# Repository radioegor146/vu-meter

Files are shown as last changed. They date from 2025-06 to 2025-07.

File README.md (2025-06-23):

# vu-meter

Physical VU meter for use with rack audio equipment

Consists of:
- 1 processor board
- 4 indicator boards (2 boards per channel)

## Processor board

The processor board is a simple board with converter from balanced input to unbalanced with 
2 x CH32X035F7P6 MCU to convert from analog domain to digital for output to SPI for shift registers.

## Indicator board

This board consists of 5 74HC595D shift registers for 35 individual LEDs.

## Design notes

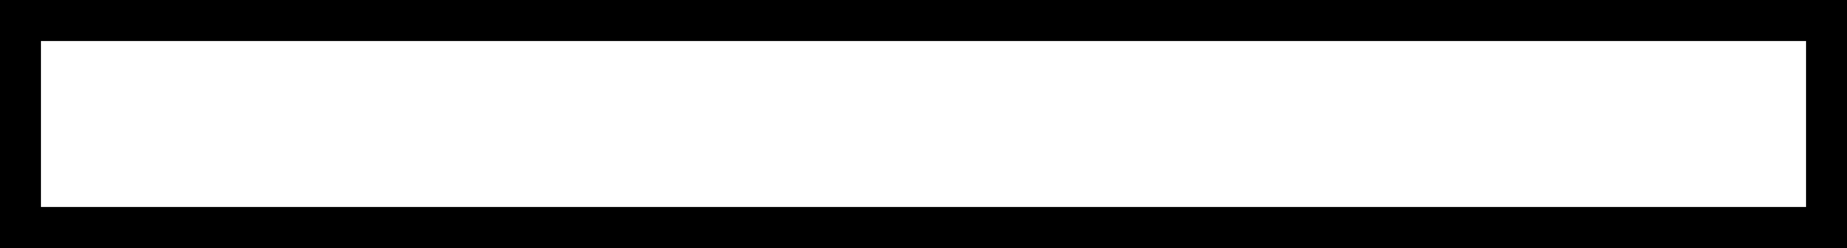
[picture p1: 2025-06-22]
front/panel-transparent-300dpi/cutout.png

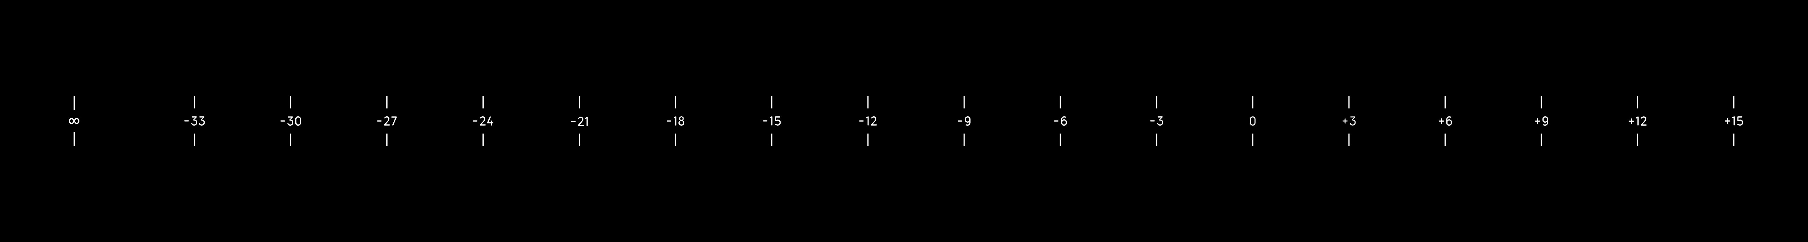
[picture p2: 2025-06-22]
front/panel-cutout-300dpi/foreground.png

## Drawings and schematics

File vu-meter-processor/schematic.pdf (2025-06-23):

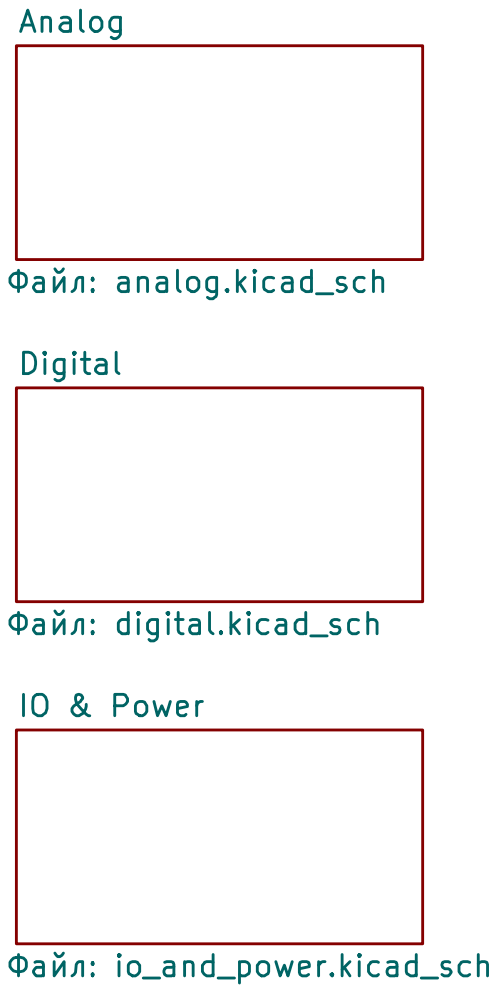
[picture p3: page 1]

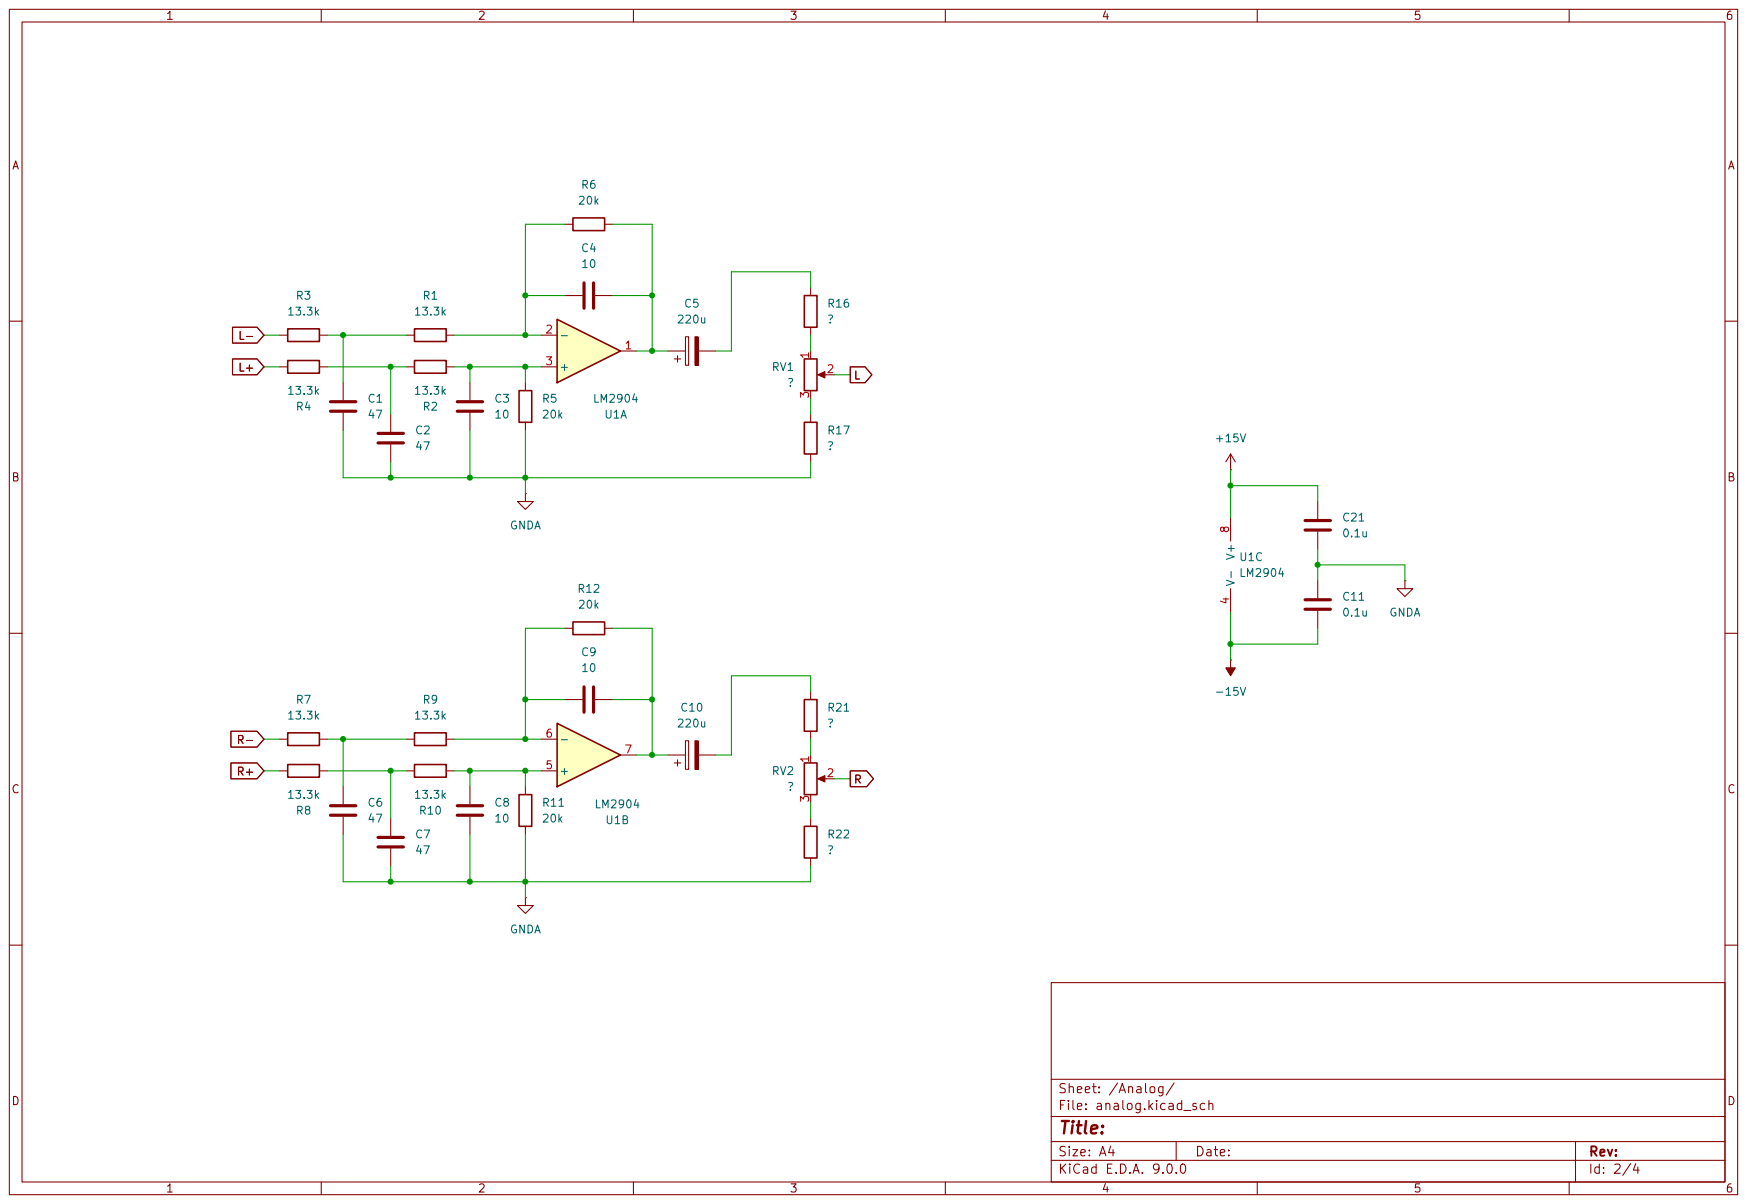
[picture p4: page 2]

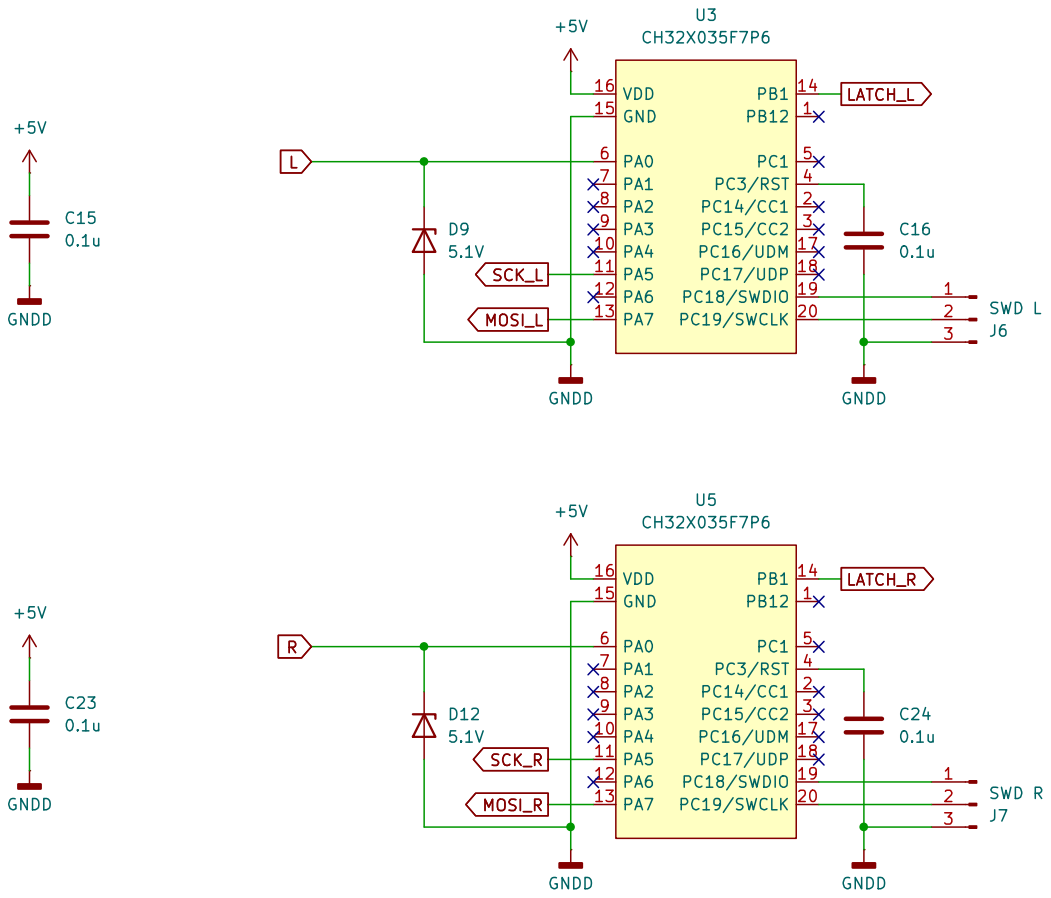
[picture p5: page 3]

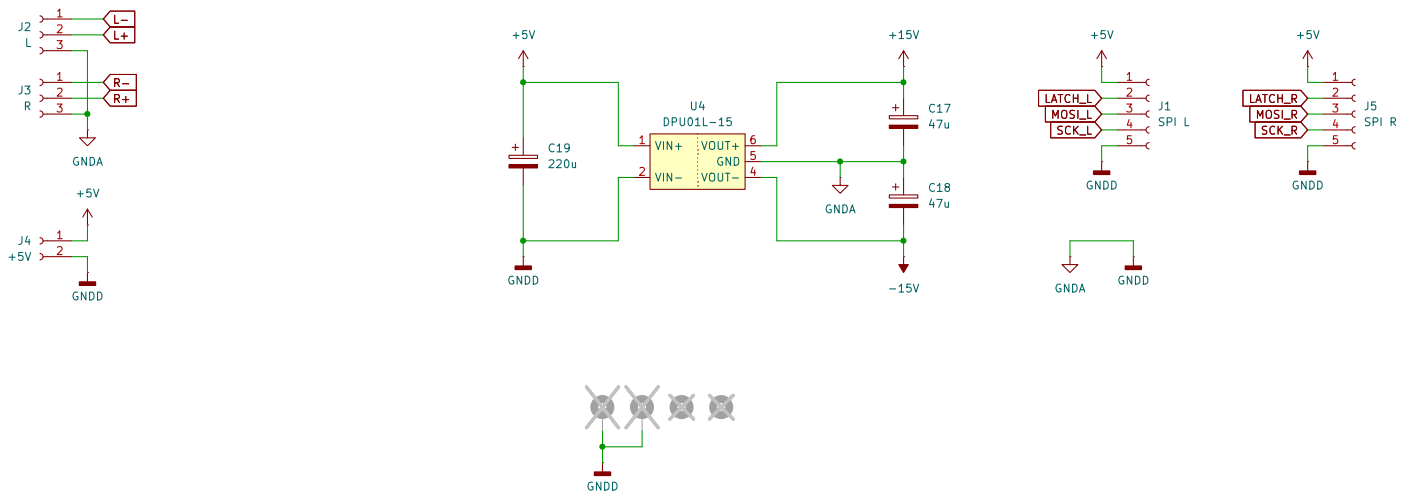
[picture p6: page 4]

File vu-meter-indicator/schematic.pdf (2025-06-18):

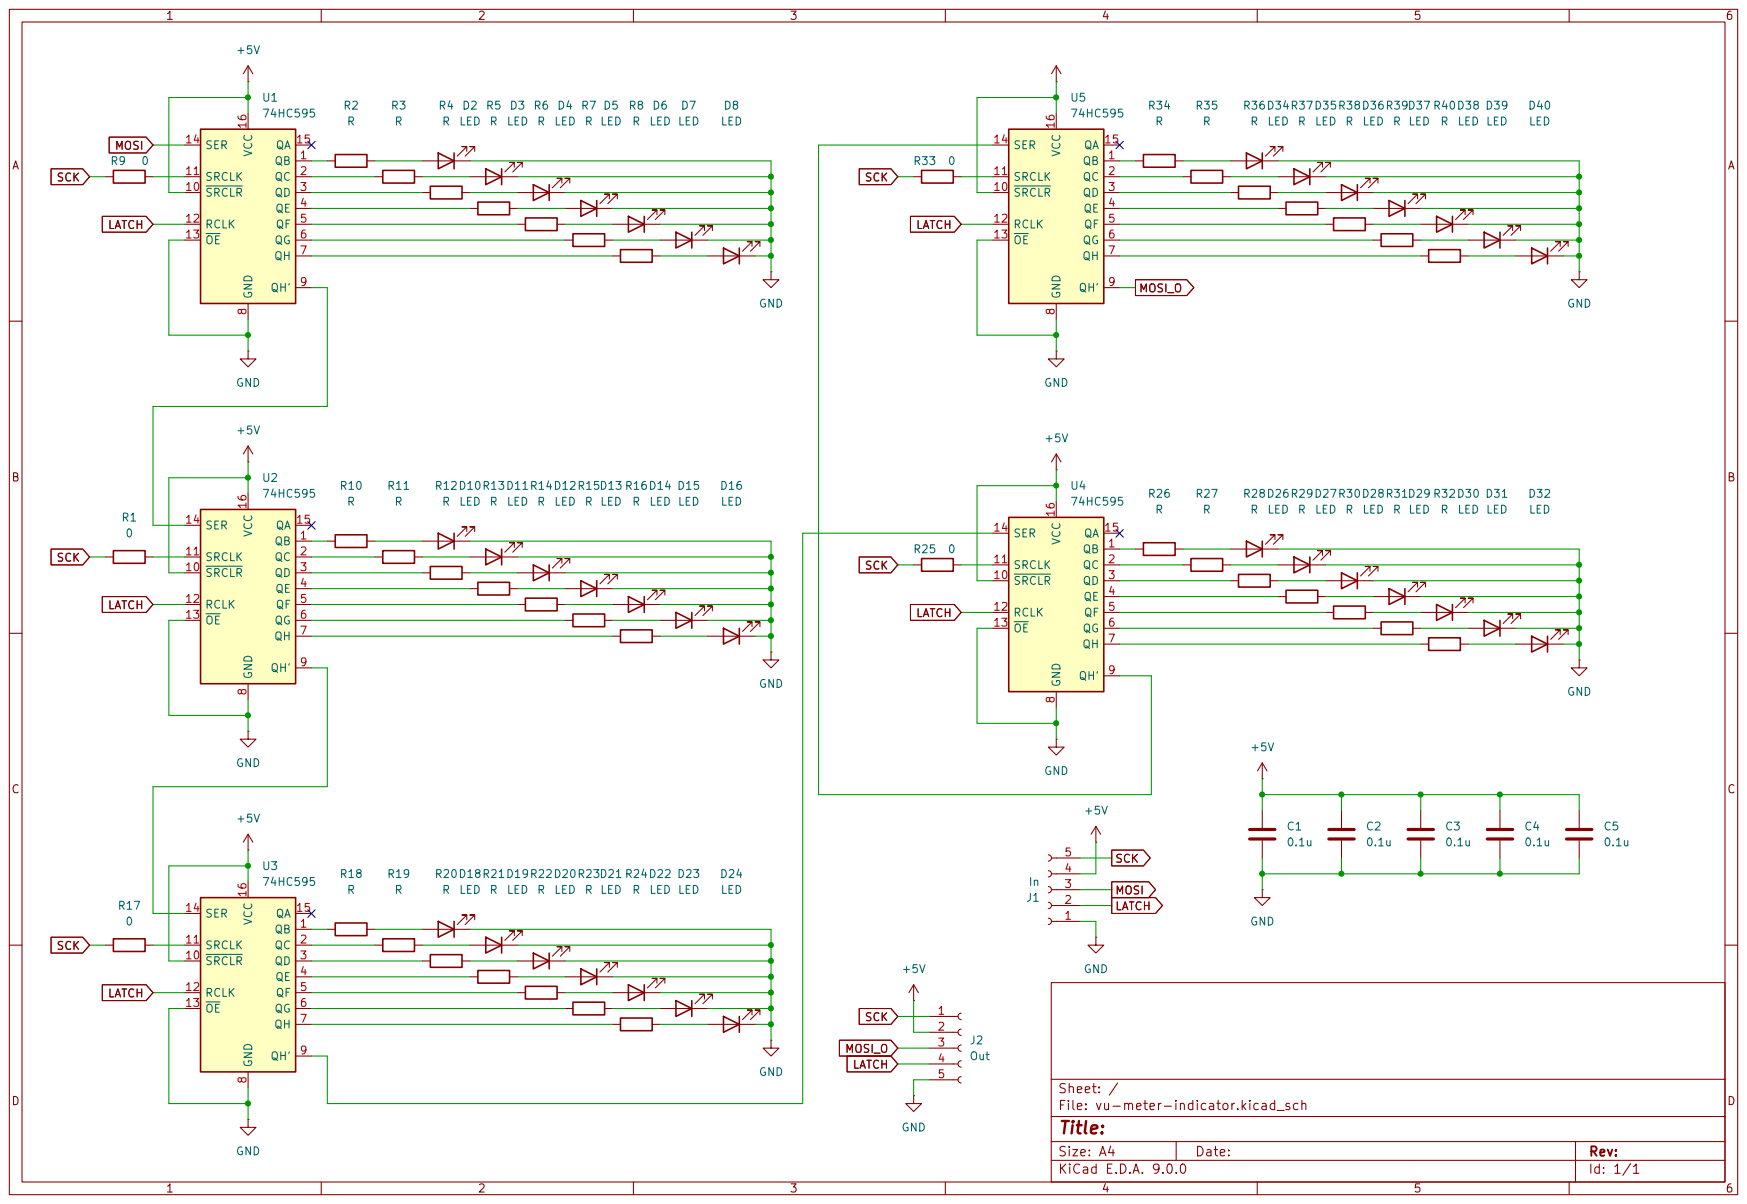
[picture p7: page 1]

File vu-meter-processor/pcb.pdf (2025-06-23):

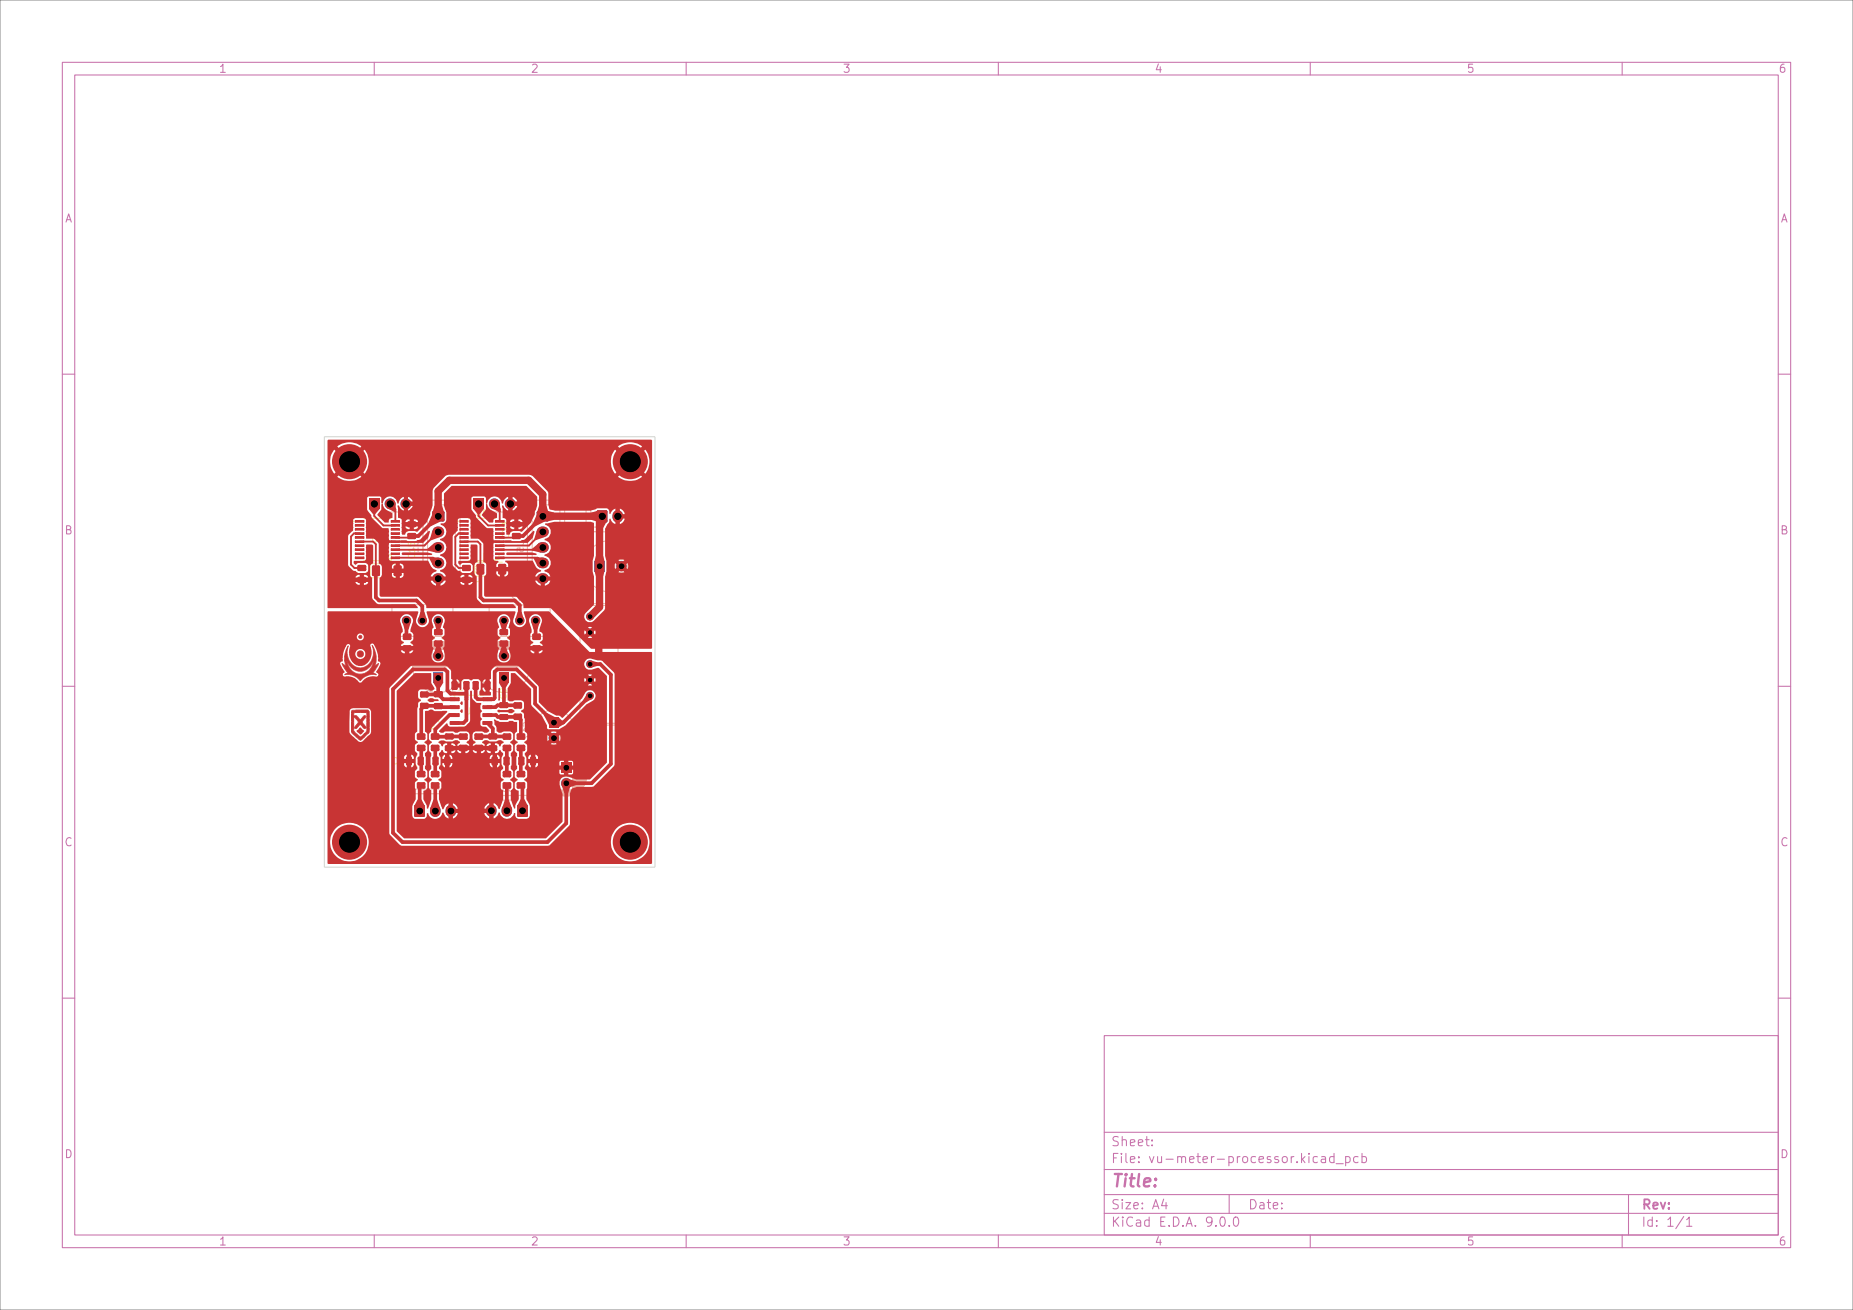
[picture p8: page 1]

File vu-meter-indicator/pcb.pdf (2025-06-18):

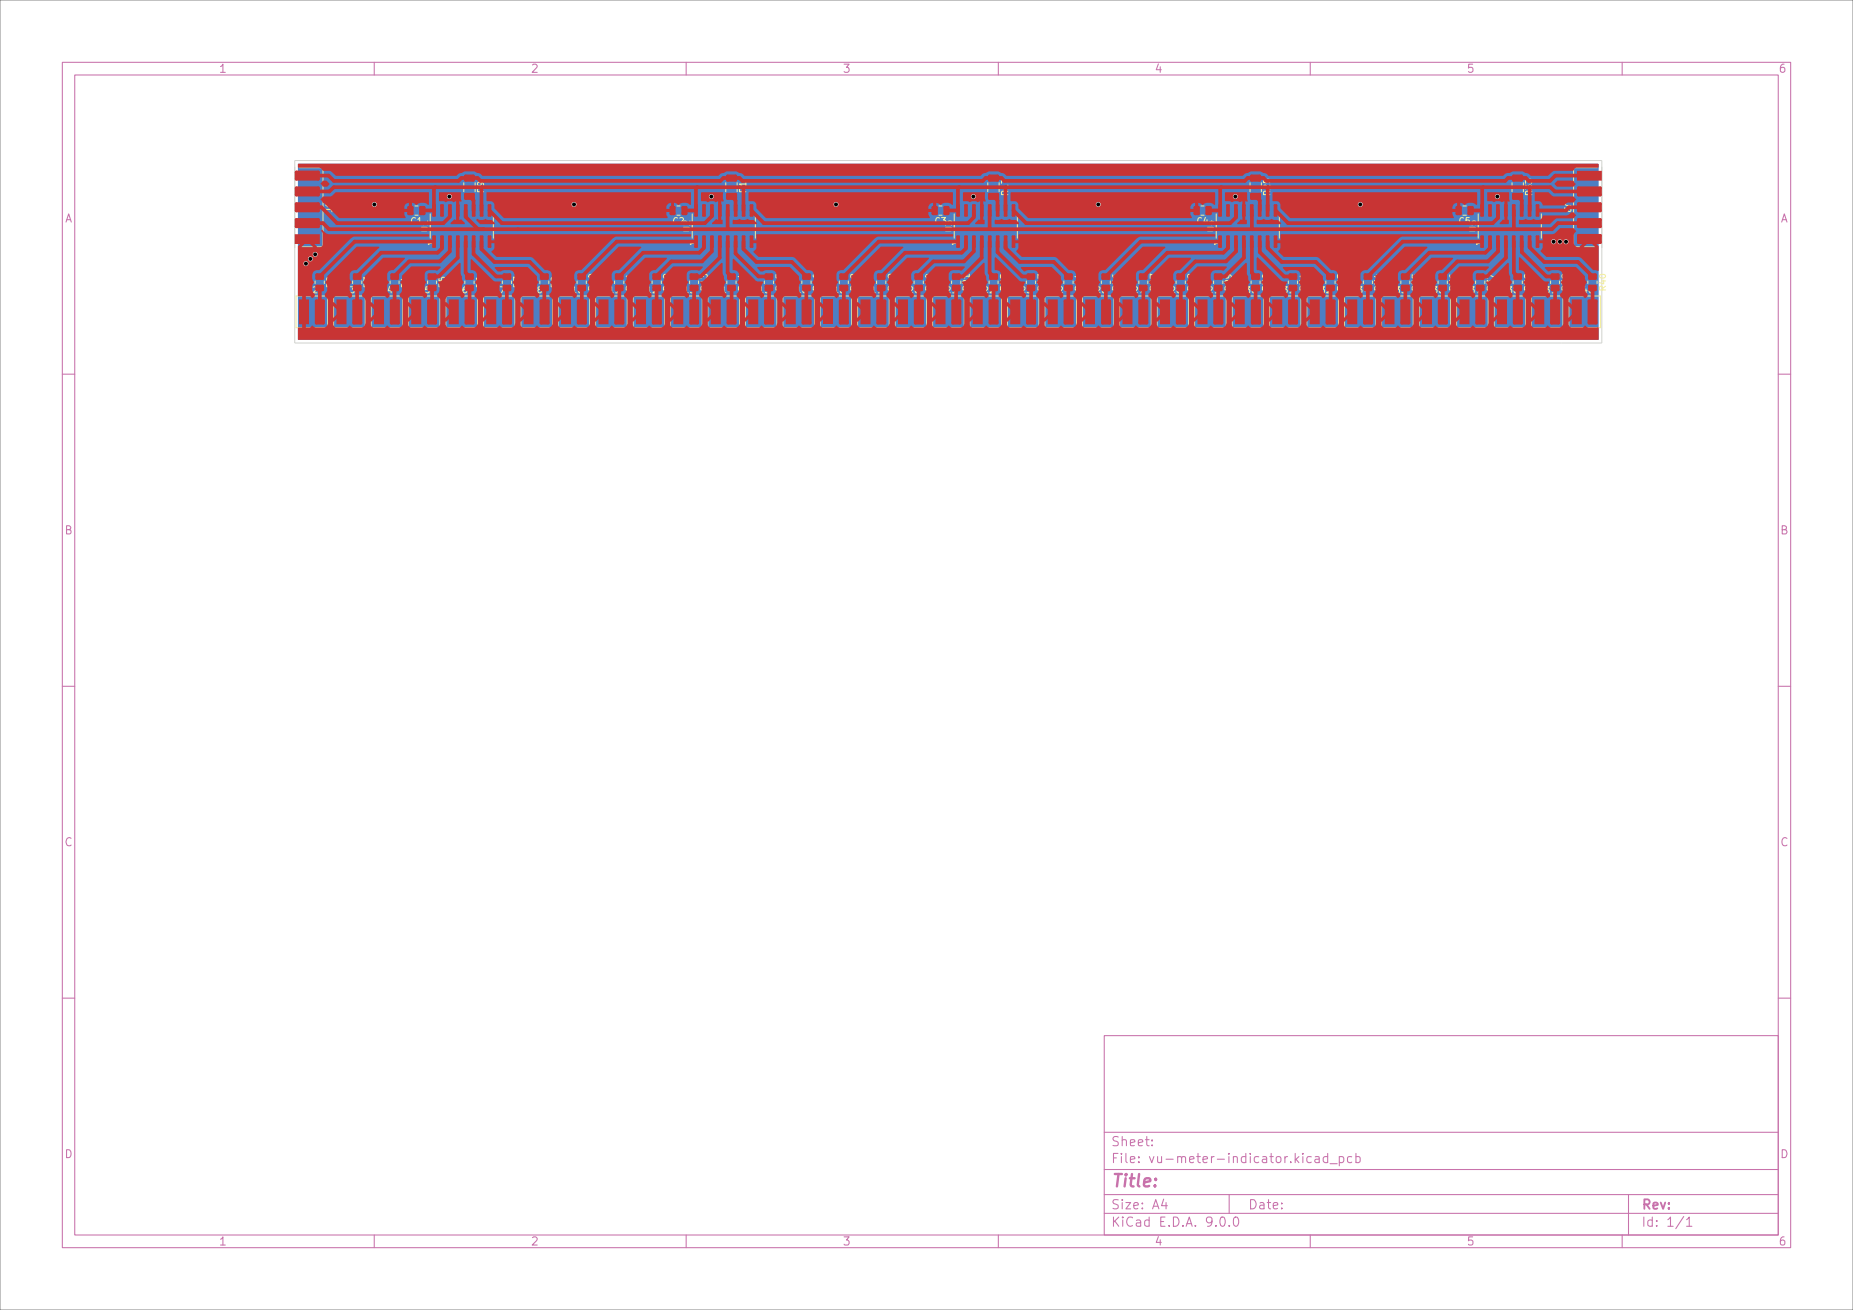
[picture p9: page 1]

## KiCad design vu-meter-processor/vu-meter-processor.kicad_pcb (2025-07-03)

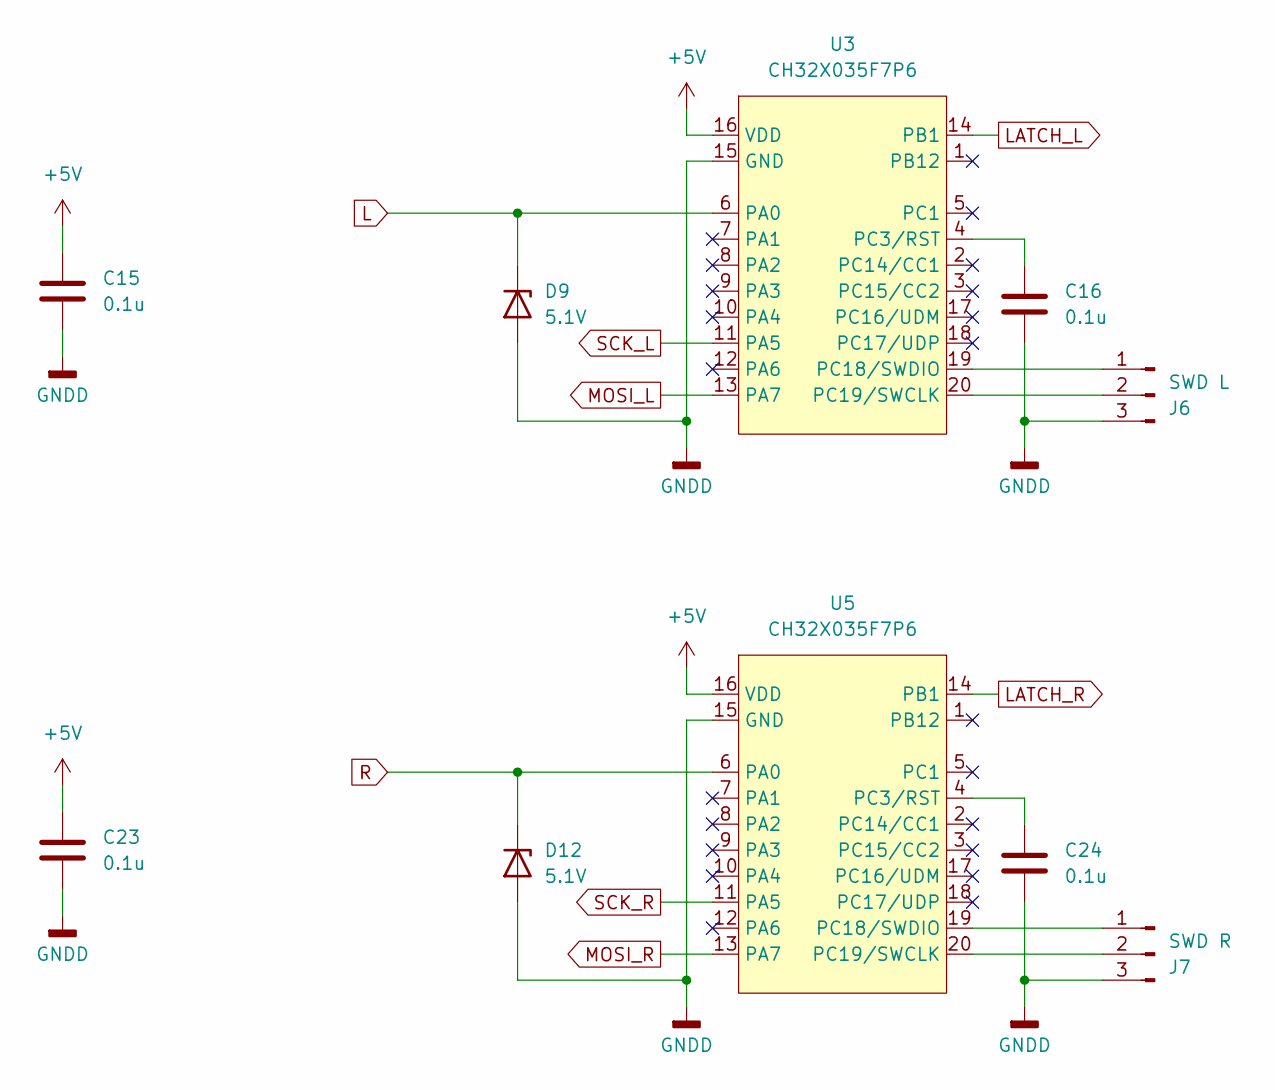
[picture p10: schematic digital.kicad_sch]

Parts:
C15, C16, C23, C24: 0.1u; C_0805_2012Metric
D9, D12: 5.1V; D_MiniMELF
J6: SWD L; PinHeader_1x03_P2.54mm_Vertical
J7: SWD R; PinHeader_1x03_P2.54mm_Vertical
U3, U5: CH32X035F7P6; TSSOP-20_4.4x6.5mm_P0.65mm

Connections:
+5V: C15.1, C23.1, U3.16 (VDD), U5.16 (VDD); also elsewhere on the board
GNDA: C15.2, C16.2, C23.2, C24.2, D9.2 (A), D12.2 (A), J6.3, J7.3, U3.15 (GND), U5.15 (GND); also elsewhere on the board
L: D9.1 (K), U3.6 (PA0); also elsewhere on the board
LATCH_L: U3.14 (PB1); also elsewhere on the board
LATCH_R: U5.14 (PB1); also elsewhere on the board
MOSI_L: U3.13 (PA7); also elsewhere on the board
MOSI_R: U5.13 (PA7); also elsewhere on the board
unnamed: J6.1, U3.19 (PC18/SWDIO)
unnamed: J6.2, U3.20 (PC19/SWCLK)
unnamed: J7.1, U5.19 (PC18/SWDIO)
unnamed: J7.2, U5.20 (PC19/SWCLK)
unnamed: C16.1, U3.4 (PC3/RST)
unnamed: C24.1, U5.4 (PC3/RST)
R: D12.1 (K), U5.6 (PA0); also elsewhere on the board
SCK_L: U3.11 (PA5); also elsewhere on the board
SCK_R: U5.11 (PA5); also elsewhere on the board

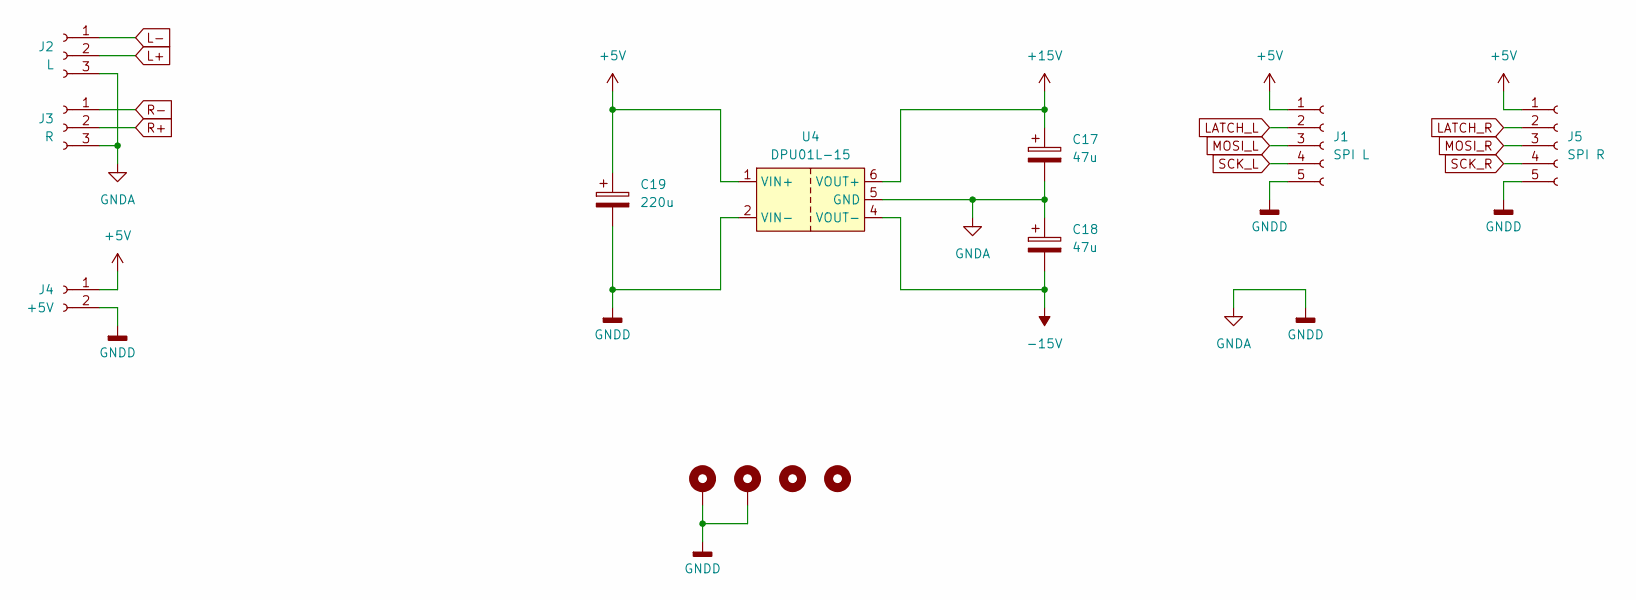
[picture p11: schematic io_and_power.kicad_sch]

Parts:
C17, C18: 47u; CP_Radial_D6.3mm_P2.50mm
C19: 220u; CP_Radial_D8.0mm_P3.50mm
H1, H2, H3, H4: MountingHole_Pad; MountingHole_3.2mm_M3_DIN965_Pad_TopOnly
J1: SPI L; JST_XH_B5B-XH-A_1x05_P2.50mm_Vertical
J2: L; JST_XH_B3B-XH-A_1x03_P2.50mm_Vertical
J3: R; JST_XH_B3B-XH-A_1x03_P2.50mm_Vertical
J4: +5V; JST_XH_B2B-XH-A_1x02_P2.50mm_Vertical
J5: SPI R; JST_XH_B5B-XH-A_1x05_P2.50mm_Vertical
U4: DPU01L-15

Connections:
+5V: C19.1, J1.1, J4.1, J5.1, U4.1 (VIN+); also elsewhere on the board
+15V: C17.1, U4.6 (VOUT+); also elsewhere on the board
-15V: C18.2, U4.4 (VOUT-); also elsewhere on the board
GNDA: C17.2, C18.1, C19.2, H1.1, H2.1, J1.5, J2.3, J3.3, J4.2, J5.5, U4.2 (VIN-), U4.5 (GND); also elsewhere on the board
L+: J2.2; also elsewhere on the board
L-: J2.1; also elsewhere on the board
LATCH_L: J1.2; also elsewhere on the board
LATCH_R: J5.2; also elsewhere on the board
MOSI_L: J1.3; also elsewhere on the board
MOSI_R: J5.3; also elsewhere on the board
R+: J3.2; also elsewhere on the board
R-: J3.1; also elsewhere on the board
SCK_L: J1.4; also elsewhere on the board
SCK_R: J5.4; also elsewhere on the board

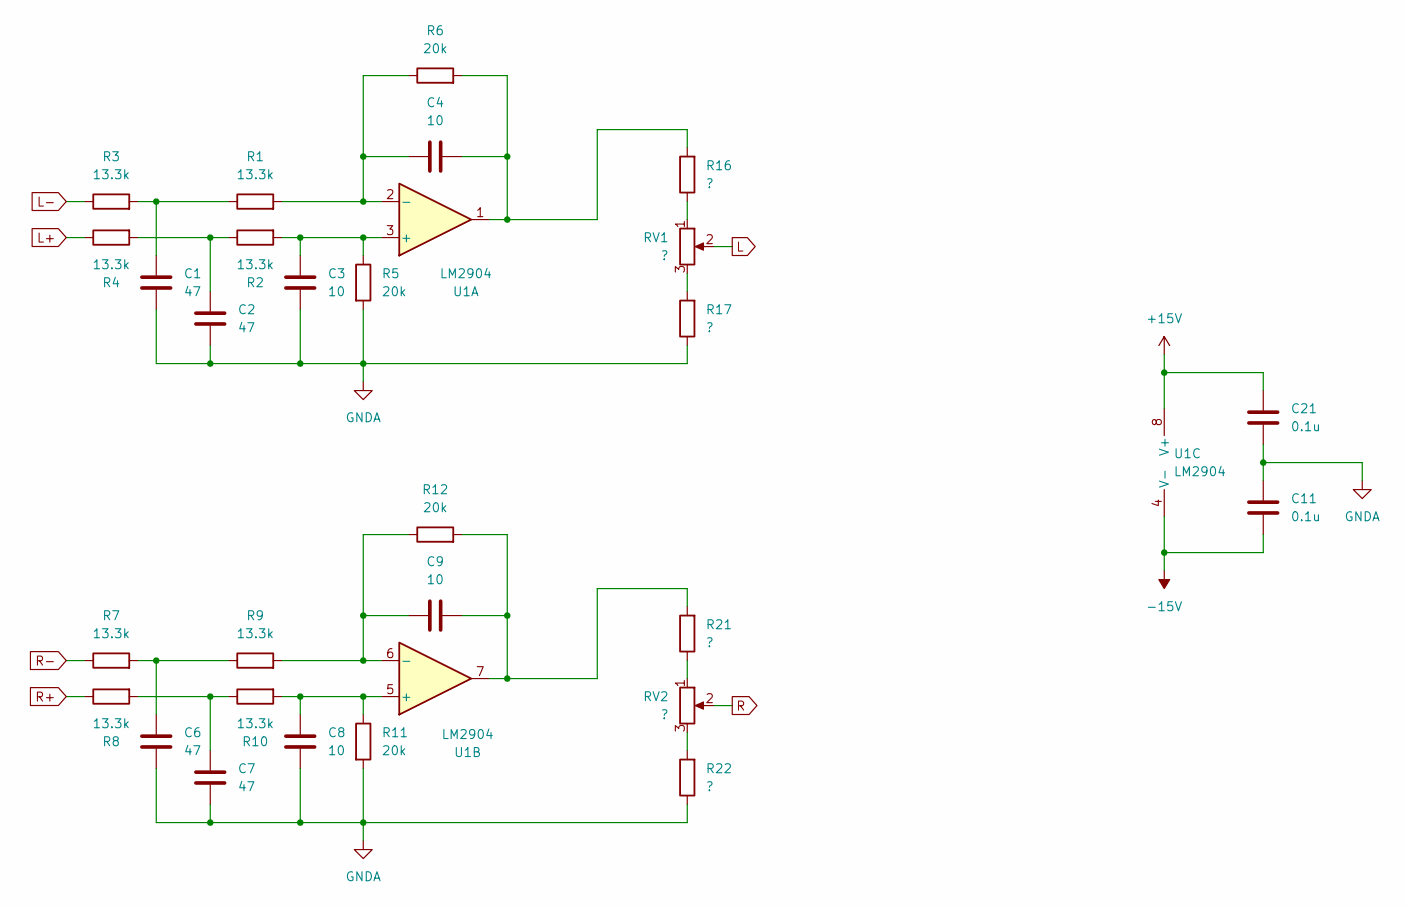
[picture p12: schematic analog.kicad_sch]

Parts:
C1, C2, C6, C7: 47; C_0805_2012Metric
C3, C4, C8, C9: 10; C_0805_2012Metric
C11, C21: 0.1u; C_0805_2012Metric
R1, R2, R3, R4, R7, R8, R9, R10: 13.3k; R_0805_2012Metric
R5, R6, R11, R12: 20k; R_0805_2012Metric
R16, R17, R21, R22: ?; R_0805_2012Metric
RV1, RV2: ?; Potentiometer_Bourns_3296W_Vertical
U1: LM2904; SOP-8_3.9x4.9mm_P1.27mm

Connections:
+15V: C21.1, U1.8 (V+); also elsewhere on the board
-15V: C11.2, U1.4 (V-); also elsewhere on the board
GNDA: C1.2, C2.2, C3.2, C6.2, C7.2, C8.2, C11.1, C21.2, R5.2, R11.2, R17.1, R22.1; also elsewhere on the board
L: RV1.2; also elsewhere on the board
L+: R4.1; also elsewhere on the board
L-: R3.1; also elsewhere on the board
unnamed: C1.1, R1.1, R3.2
unnamed: C2.1, R2.1, R4.2
unnamed: C4.2, R6.2, R16.2, U1.1
unnamed: C6.1, R7.2, R9.1
unnamed: C7.1, R8.2, R10.1
unnamed: C9.2, R12.2, R21.2, U1.7
unnamed: R16.1, RV1.1
unnamed: R17.2, RV1.3
unnamed: R21.1, RV2.1
unnamed: R22.2, RV2.3
unnamed: C3.1, R2.2, R5.1, U1.3 (+)
unnamed: C4.1, R1.2, R6.1, U1.2 (-)
unnamed: C8.1, R10.2, R11.1, U1.5 (+)
unnamed: C9.1, R9.2, R12.1, U1.6 (-)
R: RV2.2; also elsewhere on the board
R+: R8.1; also elsewhere on the board
R-: R7.1; also elsewhere on the board

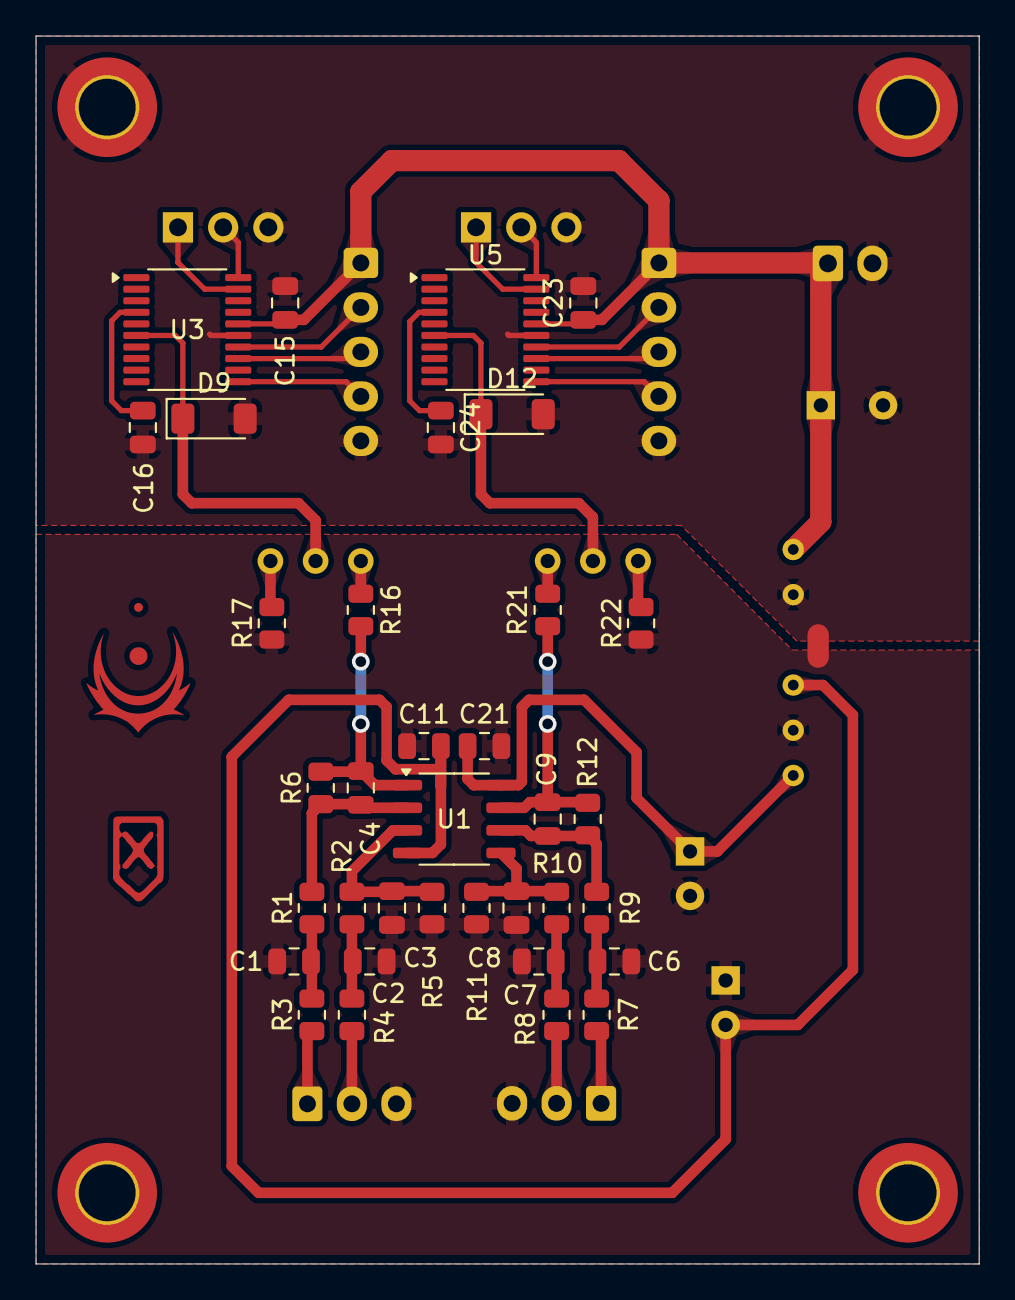
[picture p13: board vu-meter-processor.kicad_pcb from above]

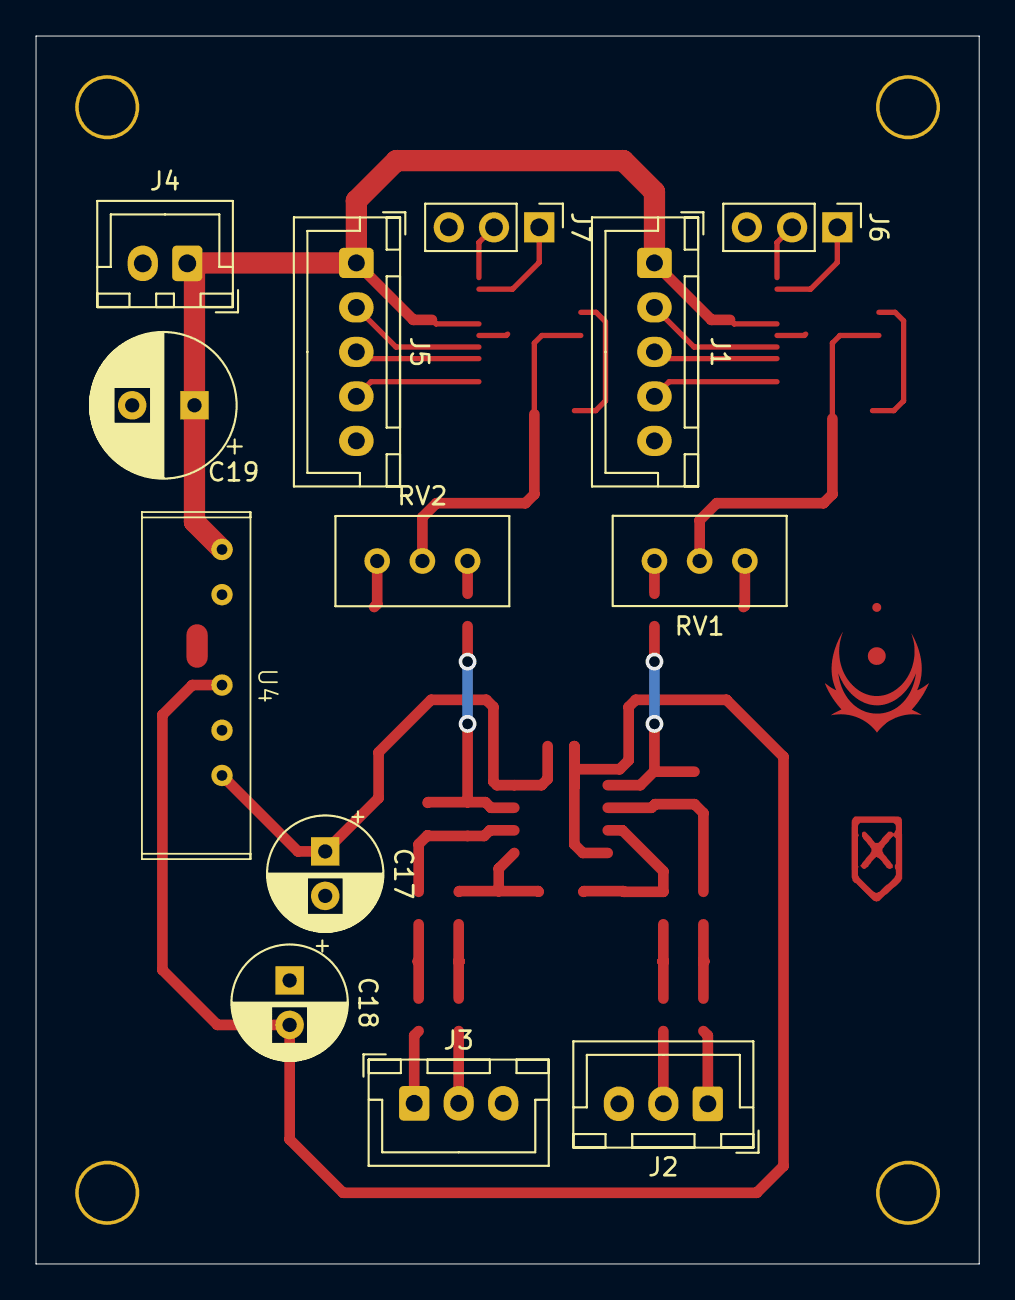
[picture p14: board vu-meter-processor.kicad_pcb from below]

Board: 2 copper layers, 53.0 x 69.0 mm, 52 parts (13 on the bottom side), 36 nets.

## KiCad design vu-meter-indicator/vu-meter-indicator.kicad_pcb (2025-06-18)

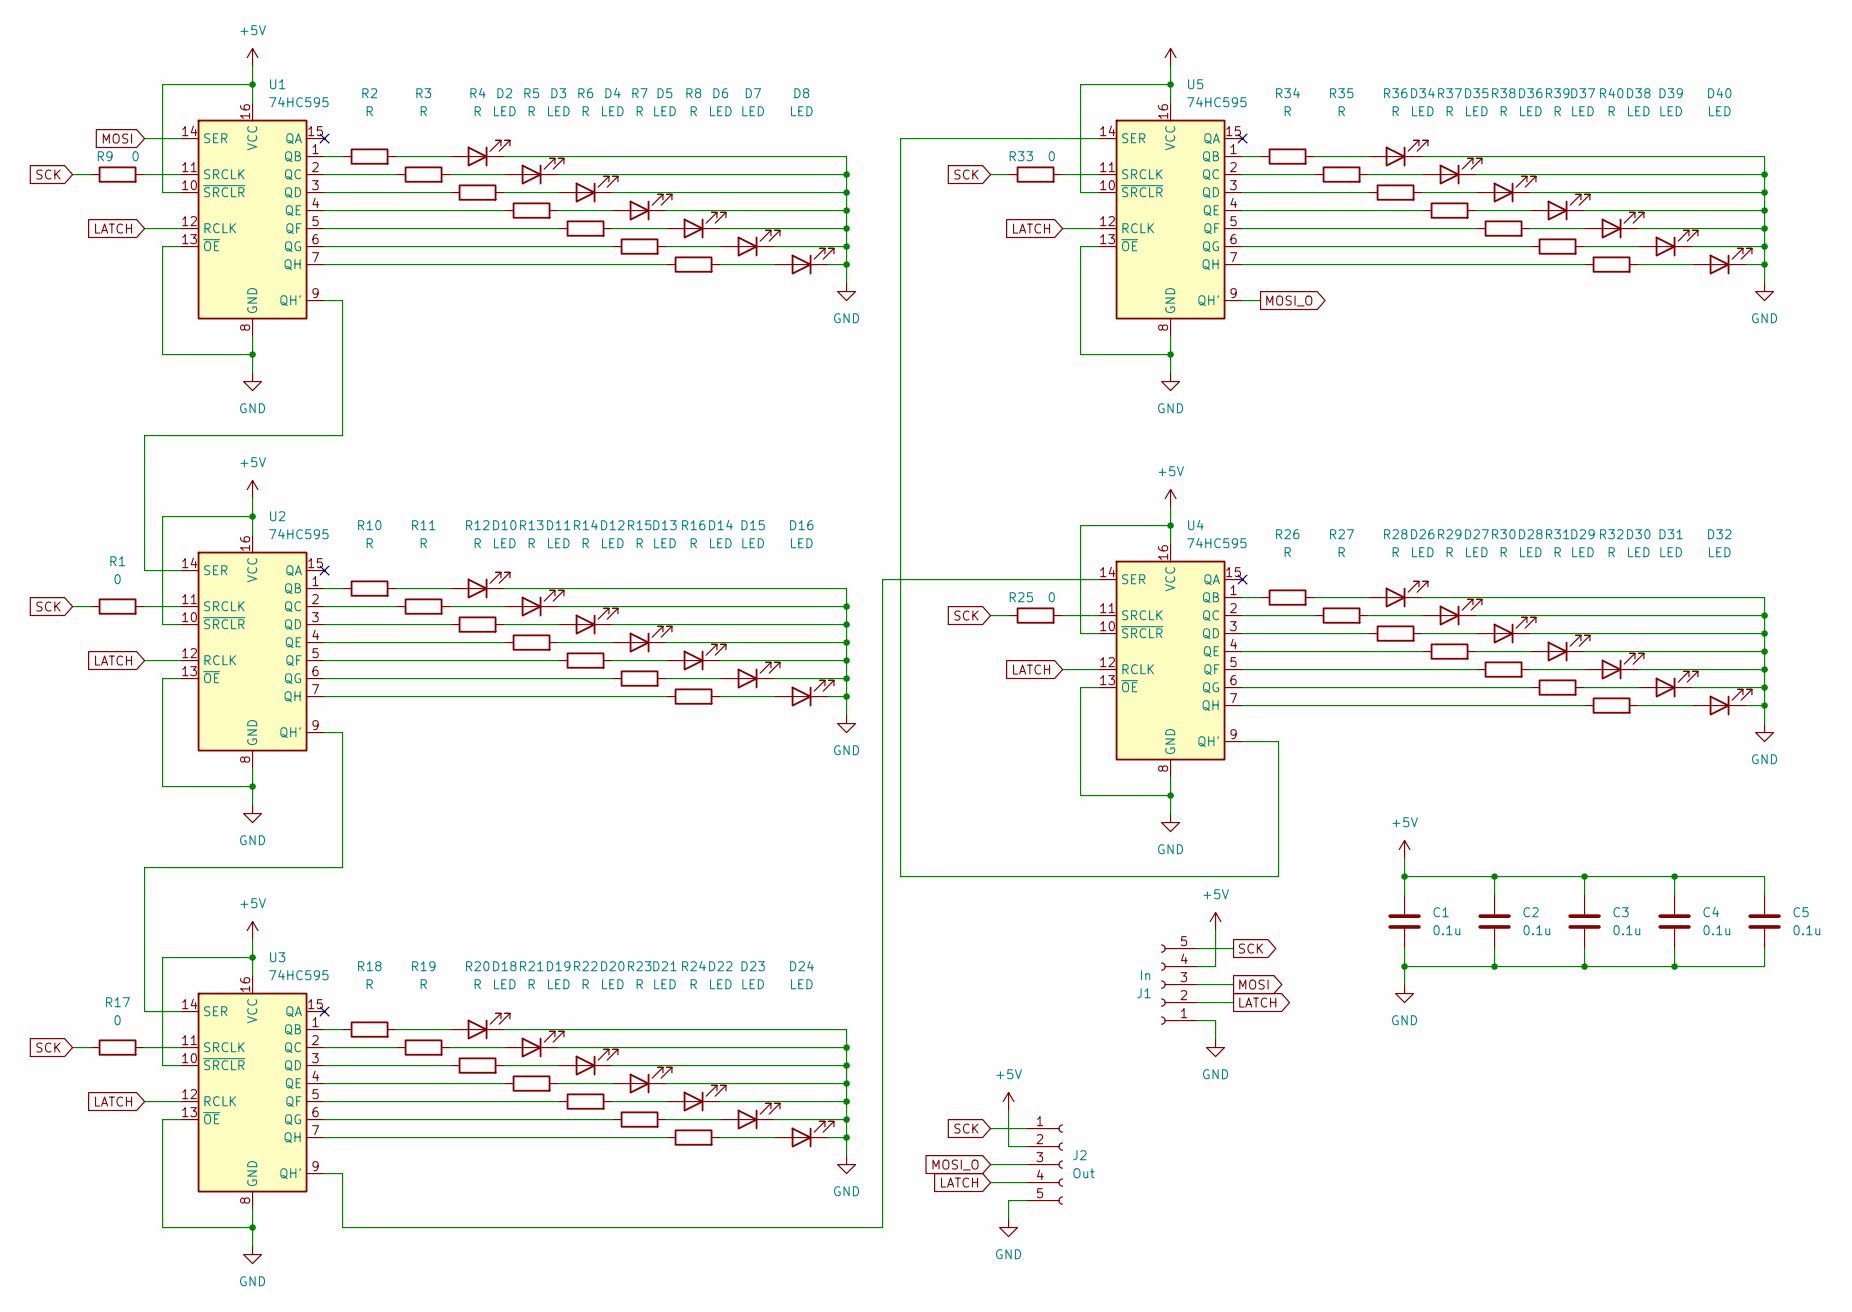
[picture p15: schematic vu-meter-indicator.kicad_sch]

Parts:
C1, C2, C3, C4, C5: 0.1u; C_0805_2012Metric
D2, D3, D4, D5, D6, D7, D8, D10, D11, D12, D13, D14, D15, D16, D18, D19, D20, D21, D22, D23, D24, D26, D27, D28, D29, D30, D31, D32, D34, D35, D36, D37, D38, D39, D40: LED
J1: In; SMD_Connector
J2: Out; SMD_Connector
R1, R9, R17, R25, R33: 0; R_1206_3216Metric
R2, R3, R4, R5, R6, R7, R8, R10, R11, R12, R13, R14, R15, R16, R18, R19, R20, R21, R22, R23, R24, R26, R27, R28, R29, R30, R31, R32, R34, R35, R36, R37, R38, R39, R40: R; R_0805_2012Metric
U1, U2, U3, U4, U5: 74HC595; SOP-16_3.9x9.9mm_P1.27mm

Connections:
+5V: C1.1, C2.1, C3.1, C4.1, C5.1, J1.4, J2.2, U1.10 (~SRCLR), U1.16 (VCC), U2.10 (~SRCLR), U2.16 (VCC), U3.10 (~SRCLR), U3.16 (VCC), U4.10 (~SRCLR), U4.16 (VCC), U5.10 (~SRCLR), U5.16 (VCC)
GND: C1.2, C2.2, C3.2, C4.2, C5.2, D2.1 (K), D3.1 (K), D4.1 (K), D5.1 (K), D6.1 (K), D7.1 (K), D8.1 (K), D10.1 (K), D11.1 (K), D12.1 (K), D13.1 (K), D14.1 (K), D15.1 (K), D16.1 (K), D18.1 (K), D19.1 (K), D20.1 (K), D21.1 (K), D22.1 (K), D23.1 (K), D24.1 (K), D26.1 (K), D27.1 (K), D28.1 (K), D29.1 (K), D30.1 (K), D31.1 (K), D32.1 (K), D34.1 (K), D35.1 (K), D36.1 (K), D37.1 (K), D38.1 (K), D39.1 (K), D40.1 (K), J1.1, J2.5, U1.8 (GND), U1.13 (~OE), U2.8 (GND), U2.13 (~OE), U3.8 (GND), U3.13 (~OE), U4.8 (GND), U4.13 (~OE), U5.8 (GND), U5.13 (~OE)
LATCH: J1.2, J2.4, U1.12 (RCLK), U2.12 (RCLK), U3.12 (RCLK), U4.12 (RCLK), U5.12 (RCLK)
MOSI: J1.3, U1.14 (SER)
MOSI_O: J2.3, U5.9 (QH')
unnamed: D2.2 (A), R2.2
unnamed: D3.2 (A), R3.2
unnamed: D4.2 (A), R4.2
unnamed: D5.2 (A), R5.2
unnamed: D6.2 (A), R6.2
unnamed: D7.2 (A), R7.2
unnamed: D8.2 (A), R8.2
unnamed: D10.2 (A), R10.2
unnamed: D11.2 (A), R11.2
unnamed: D12.2 (A), R12.2
unnamed: D13.2 (A), R13.2
unnamed: D14.2 (A), R14.2
unnamed: D15.2 (A), R15.2
unnamed: D16.2 (A), R16.2
unnamed: D18.2 (A), R18.2
unnamed: D19.2 (A), R19.2
unnamed: D20.2 (A), R20.2
unnamed: D21.2 (A), R21.2
unnamed: D22.2 (A), R22.2
unnamed: D23.2 (A), R23.2
unnamed: D24.2 (A), R24.2
unnamed: D26.2 (A), R26.2
unnamed: D27.2 (A), R27.2
unnamed: D28.2 (A), R28.2
unnamed: D29.2 (A), R29.2
unnamed: D30.2 (A), R30.2
unnamed: D31.2 (A), R31.2
unnamed: D32.2 (A), R32.2
unnamed: D34.2 (A), R34.2
unnamed: D35.2 (A), R35.2
unnamed: D36.2 (A), R36.2
unnamed: D37.2 (A), R37.2
unnamed: D38.2 (A), R38.2
unnamed: D39.2 (A), R39.2
unnamed: D40.2 (A), R40.2
unnamed: R2.1, U1.1 (QB)
unnamed: R3.1, U1.2 (QC)
unnamed: R4.1, U1.3 (QD)
unnamed: R5.1, U1.4 (QE)
unnamed: R6.1, U1.5 (QF)
unnamed: R7.1, U1.6 (QG)
unnamed: U1.9 (QH'), U2.14 (SER)
unnamed: R8.1, U1.7 (QH)
unnamed: R9.2, U1.11 (SRCLK)
unnamed: R10.1, U2.1 (QB)
unnamed: R11.1, U2.2 (QC)
unnamed: R12.1, U2.3 (QD)
unnamed: R13.1, U2.4 (QE)
unnamed: R14.1, U2.5 (QF)
unnamed: R15.1, U2.6 (QG)
unnamed: U2.9 (QH'), U3.14 (SER)
unnamed: R16.1, U2.7 (QH)
unnamed: R1.2, U2.11 (SRCLK)
unnamed: R18.1, U3.1 (QB)
unnamed: R19.1, U3.2 (QC)
unnamed: R20.1, U3.3 (QD)
unnamed: R21.1, U3.4 (QE)
unnamed: R22.1, U3.5 (QF)
unnamed: R23.1, U3.6 (QG)
unnamed: U3.9 (QH'), U4.14 (SER)
unnamed: R24.1, U3.7 (QH)
unnamed: R17.2, U3.11 (SRCLK)
unnamed: R26.1, U4.1 (QB)
unnamed: R27.1, U4.2 (QC)
unnamed: R28.1, U4.3 (QD)
unnamed: R29.1, U4.4 (QE)
unnamed: R30.1, U4.5 (QF)
unnamed: R31.1, U4.6 (QG)
unnamed: U4.9 (QH'), U5.14 (SER)
unnamed: R32.1, U4.7 (QH)
unnamed: R25.2, U4.11 (SRCLK)
unnamed: R34.1, U5.1 (QB)
unnamed: R35.1, U5.2 (QC)
unnamed: R36.1, U5.3 (QD)
unnamed: R37.1, U5.4 (QE)
unnamed: R38.1, U5.5 (QF)
unnamed: R39.1, U5.6 (QG)
unnamed: R40.1, U5.7 (QH)
unnamed: R33.2, U5.11 (SRCLK)
SCK: J1.5, J2.1, R1.1, R9.1, R17.1, R25.1, R33.1

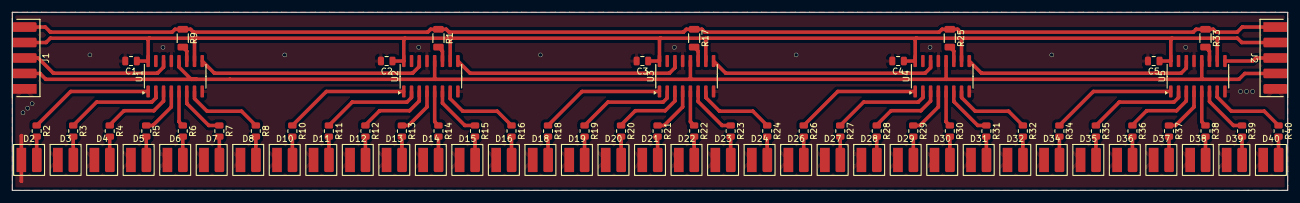
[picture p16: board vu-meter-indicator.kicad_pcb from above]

Board: 2 copper layers, 209.5 x 29.2 mm, 87 parts (0 on the bottom side), 85 nets.

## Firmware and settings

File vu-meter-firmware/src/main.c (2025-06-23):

#include <ch32x035.h>
#include <debug.h>

#include "mcu_config.h"

void GPIOInitPin(GPIO_TypeDef* gpio, uint16_t pin, GPIOSpeed_TypeDef speed,
                 GPIOMode_TypeDef mode) {
  GPIO_InitTypeDef init = {0};
  init.GPIO_Pin = pin;
  init.GPIO_Speed = speed;
  init.GPIO_Mode = mode;
  GPIO_Init(gpio, &init);
}

void GPIOInit() {
  RCC_APB2PeriphClockCmd(RCC_APB2Periph_GPIOA | RCC_APB2Periph_GPIOB, ENABLE);

  GPIOInitPin(INPUT_PORT, INPUT_PIN, GPIO_Speed_50MHz, GPIO_Mode_AIN);

  GPIOInitPin(SCK_PORT, SCK_PIN, GPIO_Speed_50MHz, GPIO_Mode_AF_PP);
  GPIOInitPin(MOSI_PORT, MOSI_PIN, GPIO_Speed_50MHz, GPIO_Mode_AF_PP);
  GPIOInitPin(LATCH_PORT, LATCH_PIN, GPIO_Speed_50MHz, GPIO_Mode_Out_PP);
}

void SPIInit() {
  RCC_APB2PeriphClockCmd(RCC_APB2Periph_SPI1, ENABLE);

  SPI_InitTypeDef init = {0};

  init.SPI_Direction = SPI_Direction_1Line_Tx;
  init.SPI_Mode = SPI_Mode_Master;
  init.SPI_DataSize = SPI_DataSize_8b;
  init.SPI_CPOL = SPI_CPOL_High;
  init.SPI_CPHA = SPI_CPHA_2Edge;
  init.SPI_NSS = SPI_NSS_Soft;
  init.SPI_BaudRatePrescaler = SPI_BaudRatePrescaler_64;
  init.SPI_FirstBit = SPI_FirstBit_MSB;
  init.SPI_CRCPolynomial = 7;

  SPI_Init(SPI1, &init);
  SPI_Cmd(SPI1, ENABLE);
}

uint8_t leds[10] = {0};

void SPISendLEDs() {
  for (int i = 0; i < sizeof(leds); i++) {
    while (SPI_I2S_GetFlagStatus(SPI1, SPI_I2S_FLAG_TXE) != SET) {}
    SPI_I2S_SendData(SPI1, leds[sizeof(leds) - i - 1]);
  }
  while (SPI_I2S_GetFlagStatus(SPI1, SPI_I2S_FLAG_TXE) != SET) {}
  while (SPI_I2S_GetFlagStatus(SPI1, SPI_I2S_FLAG_BSY) != RESET) {}

  GPIO_SetBits(LATCH_PORT, LATCH_PIN);
  Delay_Us(10);
  GPIO_ResetBits(LATCH_PORT, LATCH_PIN);
}

void SendLevel(uint8_t value) {
  for (int i = 0; i < sizeof(leds); i++) {
    leds[i] = 0;
  }
  int bit = 1;
  while (value) {
    leds[bit / 8] |= (1 << (bit % 8));
    value--;
    bit++;
    if (bit % 8 == 0) {
      bit++;
    }
  }
  SPISendLEDs();
}

void ADCInit() {
  RCC_APB2PeriphClockCmd(RCC_APB2Periph_ADC1, ENABLE);

  ADC_DeInit(ADC1);
  ADC_CLKConfig(ADC1, ADC_CLK_Div6);

  ADC_InitTypeDef init = {0};

  init.ADC_Mode = ADC_Mode_Independent;
  init.ADC_ScanConvMode = DISABLE;
  init.ADC_ContinuousConvMode = DISABLE;
  init.ADC_ExternalTrigConv = ADC_ExternalTrigConv_None;
  init.ADC_DataAlign = ADC_DataAlign_Right;
  init.ADC_NbrOfChannel = 1;
  ADC_Init(ADC1, &init);
  ADC_Cmd(ADC1, ENABLE);
}

uint16_t ADCRead() {
  ADC_RegularChannelConfig(ADC1, ADC_Channel_0, 1, ADC_SampleTime_11Cycles);
  ADC_SoftwareStartConvCmd(ADC1, ENABLE);
  while (!ADC_GetFlagStatus(ADC1, ADC_FLAG_EOC)) {}
  return ADC_GetConversionValue(ADC1);
}

void Init() {
  NVIC_PriorityGroupConfig(NVIC_PriorityGroup_2);
  GPIOInit();
  SPIInit();
  ADCInit();
  Delay_Init();
}

uint16_t kConversionMap[70] = { 11, 12, 13, 14, 15, 16, 18, 19, 21, 23, 25, 27, 30, 33, 35, 39, 42, 46, 50, 55, 60, 65, 71, 77, 84, 92, 100, 109, 119, 129, 141, 154, 168, 183, 199, 217, 237, 258, 282, 307, 335, 365, 398, 434, 473, 516, 562, 613, 668, 728, 794, 865, 944, 1029, 1121, 1223, 1333, 1453, 1584, 1727, 1883, 2052, 2237, 2439, 2659, 2899, 3160, 3446, 3756, 4095 };

uint8_t ConvertToLEDs(uint16_t value) {
  for (int i = 0; i < sizeof(kConversionMap) / sizeof(kConversionMap[0]); i++) {
    if (value < kConversionMap[i]) {
      if (i <= 1) {
        return 1;
      }
      return i - 1;
    }
  }
  return 69;
}

int main() {
  Init();

  int32_t buffered_value = 0;

  for (;;) {
    uint16_t value = ADCRead();
    int32_t real_value = value << 16;
    buffered_value = real_value > buffered_value ? real_value : buffered_value;
    SendLevel(ConvertToLEDs(buffered_value >> 16));
    if (buffered_value > 0) {
      buffered_value -= buffered_value >> 9;
    }
    if (buffered_value < 0) {
      buffered_value = 0;
    }
  }
}

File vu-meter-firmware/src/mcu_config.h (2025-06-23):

#ifndef MCU_CONFIG_H_
#define MCU_CONFIG_H_

#include <ch32x035.h>

#define INPUT_PORT GPIOA
#define INPUT_PIN GPIO_Pin_0

#define SCK_PORT GPIOA
#define SCK_PIN GPIO_Pin_5
#define MOSI_PORT GPIOA
#define MOSI_PIN GPIO_Pin_7
#define LATCH_PORT GPIOB
#define LATCH_PIN GPIO_Pin_1

#endif

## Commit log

2025-06-18 main commit
    [analog.kicad_sch, digital.kicad_sch, io_and_power.kicad_sch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]
2025-06-18 add pdfs for schematic and pcbs
2025-06-22 fix: change overall power supply to only 5V, make peak detector DNP for now
    [analog.kicad_sch, digital.kicad_sch, io_and_power.kicad_sch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]
2025-06-23 remove analog peak detector fully and split one chip into two for better inter-channel performance
    [analog.kicad_sch, digital.kicad_sch, io_and_power.kicad_sch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]
2025-07-03 fix: remove dc blocking capacitors
    [analog.kicad_sch, vu-meter-processor.kicad_pcb]
